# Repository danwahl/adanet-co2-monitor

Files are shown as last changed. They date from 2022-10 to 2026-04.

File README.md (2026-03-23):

# Adanet CO₂ Monitor

The ambient CO₂ level is important for at least three reasons:

1. Excessive CO₂ can lead to a [decline in cognitive ability and sleep quality](https://slatestarcodex.com/2018/08/23/carbon-dioxide-an-open-door-policy/)
2. CO₂ levels can be used to as a [proxy for good ventilation and COVID risk](https://www.cdc.gov/coronavirus/2019-ncov/community/ventilation.html#faq-53432-answer0)
3. You can [monitor climate change](https://www.climate.gov/news-features/understanding-climate/climate-change-atmospheric-carbon-dioxide) in real time!

The [Wirecutter-recommended](https://www.nytimes.com/wirecutter/reviews/best-home-air-quality-monitor/) CO₂ monitor for personal use is the [Aranet4](https://aranet.com/products/aranet4/), and if you're just looking for something reliable and can afford it ($250 as of writing), stop reading and go buy one of those (or for a _slightly_ cheaper option, one of [these](https://www.co2.click/)).

---

Still here? Congratulations on not taking the coward's way out. Now let's build a thing!

The Adanet CO₂ Monitor has the following features:

- CO₂ (ppm), temperature (°C), relative humidity (%), battery life (%), and pressure (hPa) sensing
- "Tri-color" E Ink screen (black, red, and white I guess?)
- Long-ish battery life (~several weeks on a single charge)
- USB-C charging (and programming!) interface
- Built-in Wi-Fi and Bluetooth for feature expansion (currently disabled in software) 

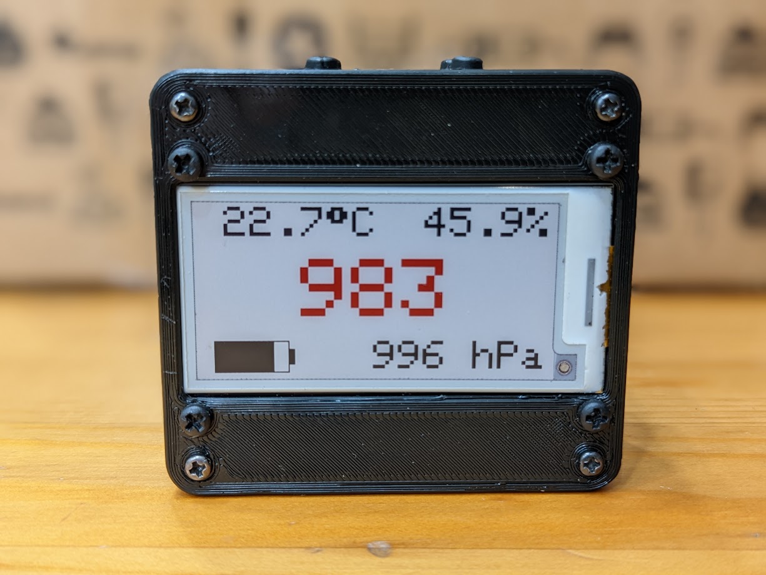
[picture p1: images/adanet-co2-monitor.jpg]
adanet-co2-monitor


## BOM

Most of the COTS parts are from [Adafruit](https://www.adafruit.com/) (hence the "Ada" prefix), but can be sourced through any of their distributors (and/or substituted for equivalents, but YMMV). Here's a snapshot of the [current BOM and pricing from Octopart](https://octopart.com/bom-tool/mcNhRVmk):

| Qty |  MPN | Part Description | Unit Price | Batch Total |
|:---:|:----:|:---:|:---:|:---:|
| 1 | 5477 | Adafruit Esp32-S3 Feather With 4Mb Flash 2Mb Psram - Stemma Qt / Qwiic | 17.5 | 17.5 |
| 1 | 4814 | Adafruit 2.13 Hd Tri-Color Eink / Epaper Display Featherwing - 250X122 Rw Panel With Ssd1680 | 24.95 | 24.95 |
| 1 | 5187 | Adafruit SCD-40 - True CO2 Temperature and Humidity Sensor | 49.5 | 49.5 |
| 1 | 4494 | Adafruit DPS310 Precision Barometric Pressure/Altitude Sensor - STEMMA QT/Qwiic | 6.95 | 6.95 |
| 1 | 2011 | Lithium Ion Battery - 3.7V 2000mAh | 12.5 | 12.5 |
| 2 | 4399 | STEMMA QT / Qwiic JST SH 4-Pin Cable - 50mm Long | 0.95 | 1.9 |
| | | | | 113.30 |

(Note that the [SCD-41](https://www.adafruit.com/product/5190) can be used as a drop-in replacement.)

In addition, you'll need several fasteners. Most come in the [Adafruit 3299](https://www.adafruit.com/product/3299) kit, but this is overkill (only 20 out of the 380 pieces are used), so you may have better luck at a hardware store [or](https://smile.amazon.com/gp/product/B018TH1NEM) [on](https://smile.amazon.com/gp/product/B012TAF8AK) [Amazon](https://smile.amazon.com/gp/product/B08F1XFQ7R). Either way, you'll need:

| Qty | Part Description | Material |
|:---:|:---:|---|
| 8 | M2.5 Hex Nut | Nylon |
| 8 | M2.5 x 6mm Screw | Nylon |
| 4 | M2.5 x 6mm M-F Hex Standoff | Nylon |
| 4 | M2.6 x 5mm Self-Tapping Screw | Steel |

I also bought the self-tapping screws in [a kit](https://smile.amazon.com/dp/B081DVZMHH), but there are [other](https://smile.amazon.com/gp/product/B00GDYDCC0) [options](https://smile.amazon.com/gp/product/B01L7PDGXO) too.

Finally, you'll need to 3D print the "top" and "bottom" pieces. If you don't have a 3D printer, either ask someone who does (these are relatively easy parts), visit to a local maker space (maybe even [your library?](https://www.chipublib.org/maker-lab/)), or use a service like [(3D)Hubs](https://www.hubs.com/). (Note: I recommend printing the "top" upside down, both to get a smooth finish on the outside and to avoid unnecessary overhangs.)

If you want to modify the design or are just curious, the parametric model is available at [OnShape](https://cad.onshape.com/documents/5da5dcb1f603a01f8bec88c9/w/ca967a8a956dc66b8484bce3/e/ef1ece94c6975fbb49878b31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).

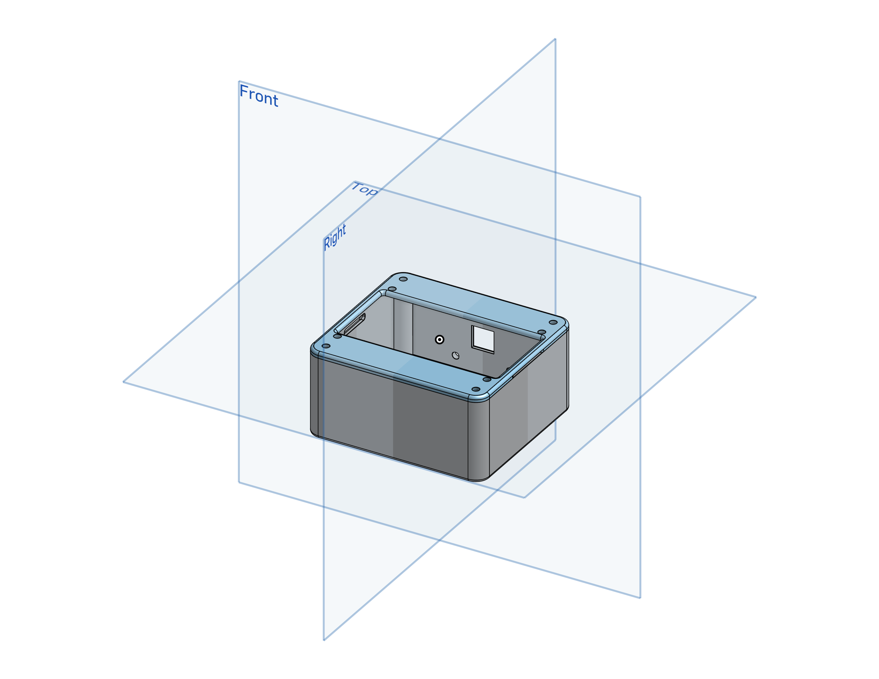
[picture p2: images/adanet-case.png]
adanet-case


## Assembly

First assemble the top and bottom of the case separately:

### Top

1. Attach the Feather board to the FeatherWing display as shown [here](https://learn.adafruit.com/adafruit-2-13-eink-display-breakouts-and-featherwings/wiring) (under "FeatherWing Connection")
2. Screw the assembly into the underside using 4 M2.5 x 6mm screws and 4 M2.5 hex nuts. Make sure that the flexible PCB on the FeatherWing (on the right in the image below) fits into the rectangular slot!

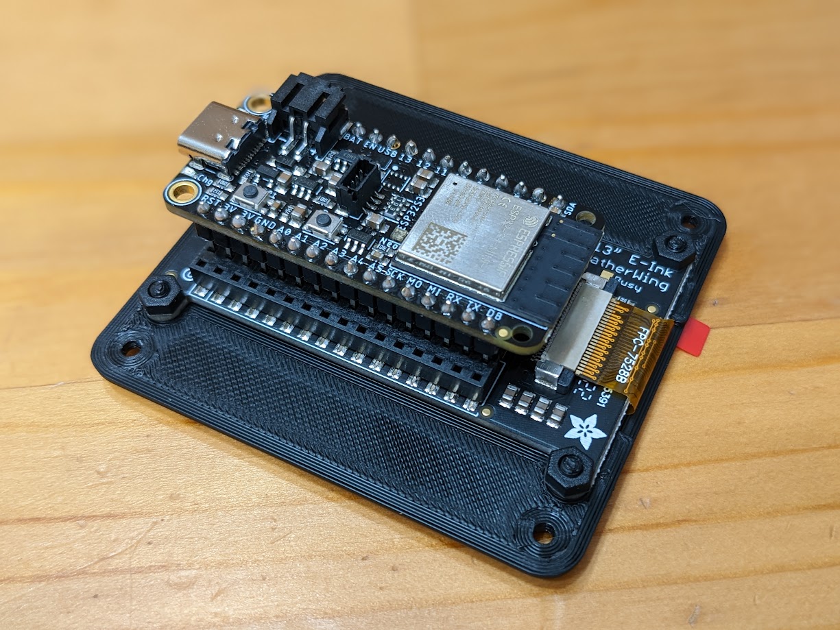
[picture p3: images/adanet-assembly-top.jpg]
adanet-assembly-top


### Bottom

1. Use 4 M2.5 x 6mm screws to attach the 4 M2.5 x 6mm M-F hex standoffs to the inside of the case (using the holes that border the the sensor slot)
2. Attach the 4-pin STEMMA QT cables to either side of the SCD4x board
3. Press the SCD4x board onto the four exposed standoffs, with the sensor facing "out" of the case, and use 2 M2.5 hex nuts to secure to the bottom two standoffs
4. Connect the DPS310 to the 4-pin STEMMA QT cable on the "right" (when facing the non-sensor side) of the SCD4x board
5. Use 2 M2.5 hex nuts to attach the DPS310 to the top two standoffs, back-to-back with the SCD4x so that the sensor is facing "in" (note: first apply Kapton/electrical tape to the back of the DPS310 to avoid shorting to the SCD4x)
6. Carefully insert the battery, which should fit snugly lengthwise, and adjacent to the bottom standoffs holding the SCD4x (note: you can use double-sided tape securely affix the battery to the case)

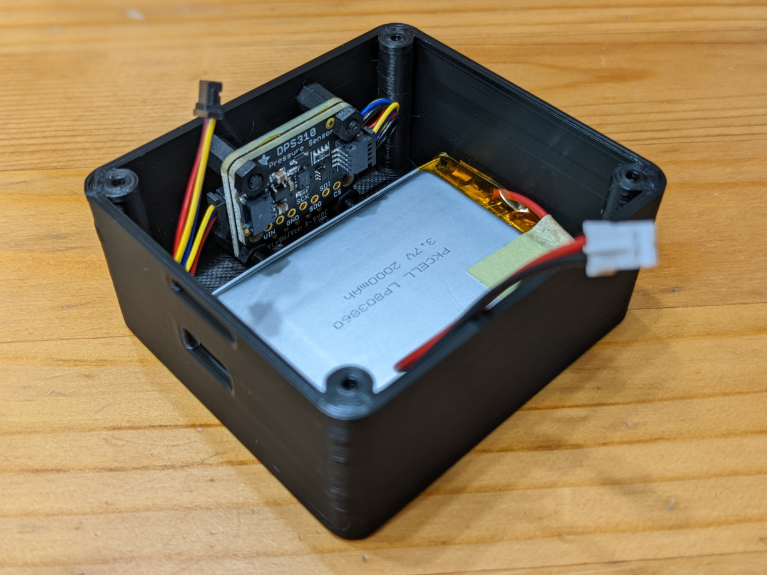
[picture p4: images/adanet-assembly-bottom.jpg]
adanet-assembly-bottom


Once both the top and bottom are assembled, connect the remaining 4-pin STEMMA QT and battery to the Feather board (middle and side connectors respectively). Close the lid to ensure a good fit, but don't install the 4 M2.3 x 5mm self-tapping screws until loading the firmware (as the BOOT/DFU and Reset buttons are not externally accessible)!

Once complete, your final assembly should look like this:

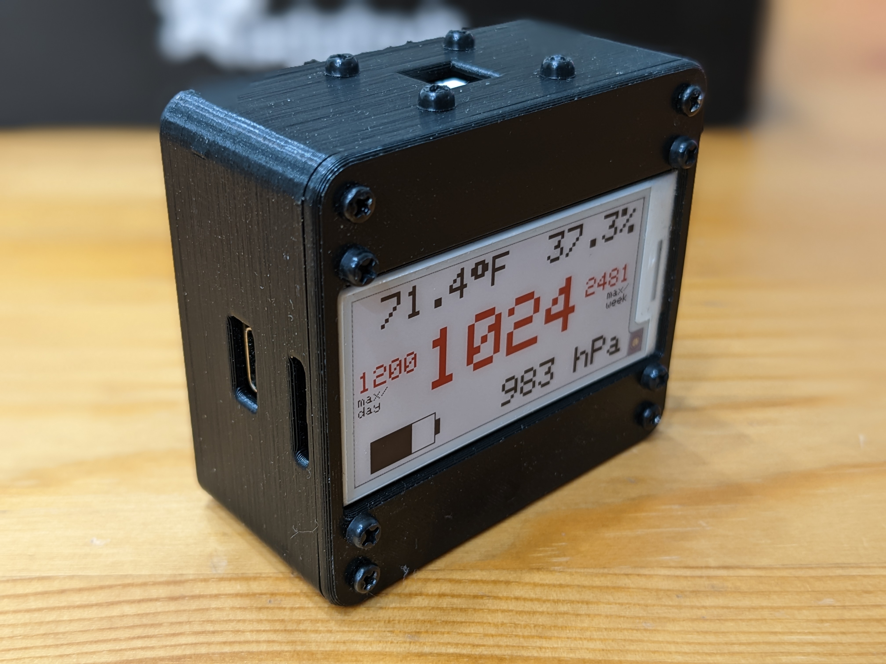
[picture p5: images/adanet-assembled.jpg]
adanet-assembled


## Firmware

The Arduino firmware (adanet-co2-monitor.ino) has been tested using the following software (and corresponding versions):

- Arduino IDE (v1.8.19 or v2.0.0)
- Adafruit DPS310 (v1.1.5)
- Adafruit EPD (v4.6.7)
- Adafruit LC709203F (v1.3.4)
- ESP32 Arduino (v3.3.5)
- Sensirion I2C SCD4x (v1.1.0)

### Development environment

To prepare your development environment:

1. Install [Arduino IDE](https://www.arduino.cc/en/software/) (and optionally the [VS Code extension](https://github.com/microsoft/vscode-arduino))
2. Follow [these instructions](https://docs.espressif.com/projects/arduino-esp32/en/latest/installing.html) to install the ESP32 Arduino library
3. Using the Library Manager (Tools/Manage Libraries...), install the remaining libraries listed above
4. Under Tools/Board (or Arduino: Board Config), select the "Adafruit Feather ESP32-S3 2MB PSRAM" option
5. In the same menu, change "USB Mode" to "Hardware CDC and JTAG" (see [here](https://github.com/espressif/arduino-esp32/issues/6762)) and "Upload Mode" to "UART0/Hardware CDC"
6. Plug in your Feather using the USB-C connector, and set the Port to match the one assigned by your OS (e.g. `COM5` on Windows, `/dev/ttyACM0` on Linux)

### Loading firmware

To load the firmware on the device:

1. Clone this repository somewhere sensible (Arduino projects are typically located in the `$HOME/Documents/Arduino` folder)
2. While holding the BOOT/DFU button, press and release the Reset button, putting the Feather into [ROM bootloader mode](https://learn.adafruit.com/adafruit-esp32-s2-feather/factory-reset)
3. If loading firmware for the first time, initialize and calibrate the sensor using the [adanet-init](adanet-init) program
4. In Arduino (or VS Code using the [Arduino extension](https://github.com/microsoft/vscode-arduino)), open the arduino-co2-monitor.ino file and click Upload (or run the Arduino: Upload task in VS Code)
5. Once finished, you may have to manually press the Reset button again to start the firmware

### Pseudocode

And that's it! The firmware does the following once every 180 seconds (the [fastest update rate](https://learn.adafruit.com/adafruit-2-13-eink-display-breakouts-and-featherwings/usage-expectations) supported by the E Ink screen):

1. Enable the SCD4x and DPS310 sensors, start measurements
2. Read battery charge state from the LC709203F sensor
3. Light sleep for 5 seconds while the initial CO₂ and pressure measurements are taking place
4. Update SCD4x with ambient pressure (the [nominal reason](http://www.co2meters.com/Documentation/AppNotes/AN149-Senseair-Pressure-Dependence.pdf) for the DPS310 sensor!)
5. Discard initial measurements (as per [SCD4x Low Power Operation](https://sensirion.com/media/documents/077BC86F/62BF01B9/CD_AN_SCD4x_Low_Power_Operation_D1.pdf)) and light sleep for another 5 seconds
6. Save new measurements and disable I2C power (turns off all sensors)
7. Enable the E Ink screen and update the display using the saved measurements
8. Deep sleep for ~170 seconds and repeat

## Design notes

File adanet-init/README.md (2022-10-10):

# Adanet Init

This is a helper program to initialize and calibrate an Adanet device. If using to calibrate, first update `CO2_AMBIENT` to the actual value (note that local CO₂ concentration is often higher than global ambient levels, e.g. [during nighttime in cities](https://www.sciencedirect.com/science/article/abs/pii/S0269749101002561?via%3Dihub).)

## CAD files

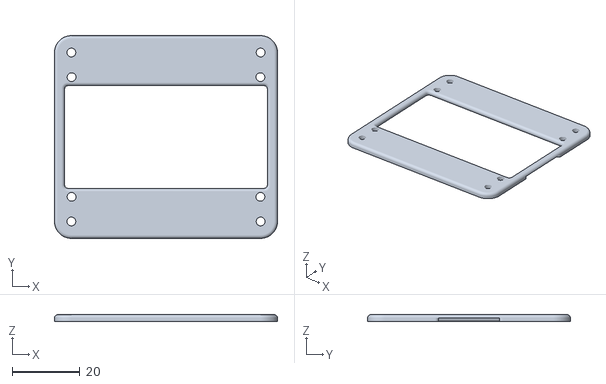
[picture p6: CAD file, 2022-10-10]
adanet-case-top.stl
66.0 x 60.0 x 2.00

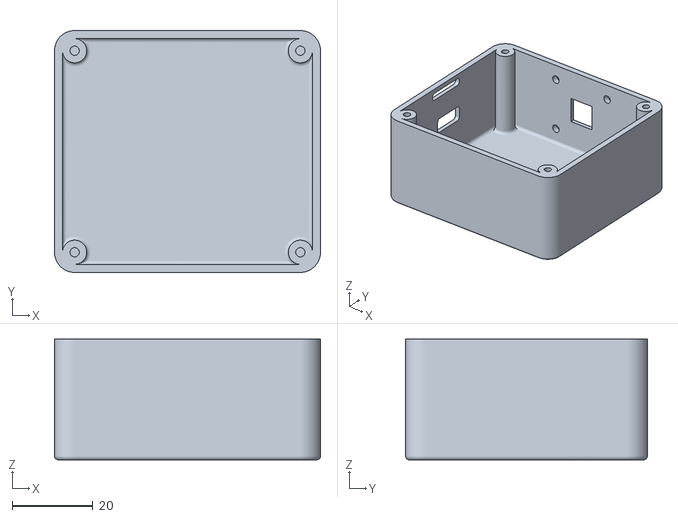
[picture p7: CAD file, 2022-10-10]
adanet-case-bottom.stl
66.0 x 60.0 x 30.0

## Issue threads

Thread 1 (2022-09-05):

Investigate Adafruit GFX fonts

danwahl, 2022-09-05:
Currently using the "classic" fixed-space bitmap font, but FreeMono would probably look better

danwahl, 2022-10-03:
Looked into this briefly and:

- The `FreeMono` font family isn't a big improvement over the built-in glxfont
- Would need to add a size bigger than the largest currently available (24pt)

Doesn't seem worth it for now

Closed 2022-10-03.

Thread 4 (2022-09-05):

Manual calibration software/instructions

danwahl, 2022-09-05:
Automatic Self Calibration is currently disabled, as per the [Low Power Operations](https://sensirion.com/media/documents/077BC86F/62BF01B9/CD_AN_SCD4x_Low_Power_Operation_D1.pdf) document:

> ASC is not supported for power cycled single shot operation.

It's not clear how often/badly the SCD4x goes out of calibration, but it might be necessary to create software/instructions for manual calibration.

Closed 2022-10-10.

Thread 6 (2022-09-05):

Address initial misc. software TODOs

danwahl, 2022-09-05:
- [x] Make `neoPixel` `static`, move initialization to `setup()` for consistency
- [x] Remove deprecated altitude correction once pressure sensor is verified
- [x] Improve (or in most cases, implement non-existent) error handling

Closed 2022-10-10.

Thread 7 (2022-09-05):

Investigate electrical modifications for reduced power consumption

danwahl, 2022-09-05:
- [ ] The E Ink screen has some low-hanging fruit, since both the `Reset` and `Busy` pins are [not currently wired up](https://learn.adafruit.com/adafruit-2-13-eink-display-breakouts-and-featherwings/pinouts) (see "Featherwing Connections"). See the [MagTag section on Arduion Sleep](https://learn.adafruit.com/adafruit-magtag/arduino-sleep) for more info
- [ ] Could remove the LED on the SCD4x (and DPS310). Also switch SCD4x to [Vin for sensor power](https://learn.adafruit.com/adafruit-scd-40-and-scd-41)?

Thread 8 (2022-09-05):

Verify that the SCD40 works as a drop-in replacement for the SCD41

danwahl, 2022-09-05:
The [Low Power Operation document](https://sensirion.com/media/documents/077BC86F/62BF01B9/CD_AN_SCD4x_Low_Power_Operation_D1.pdf) says:

> Power Cycled Single Shot Operation (SCD41 only)

But the firmware is not currently using single-shot operation, so I don't think this applies.

 Still, worth verifying before purchasing SCD40s in bulk!

danwahl, 2022-10-03:
I verified this, but still purchased the SCD41 for the first build round (since it was in stock). Given the functionality currently being used, I don't think it matters which of the SCD4x sensors is used. Keeping this open as a reminder to adjust the README accordingly.

danwahl, 2022-10-10:
I confirmed that the SCD40 works using the periodic measurement mode, same as the SCD41 (which is expected).

I then tried to use the "Power Cycled Single Shot Operation" as described in the above document (which required modifying the [arduino-i2c-scd4x](https://github.com/danwahl/arduino-i2c-scd4x/tree/idle-single-shot) library) but was getting suspicious temperature/humidity readings.

I'm not 100% sure that using the sensor in periodic measurement mode for two samples is a valid way to do low-power operation, and so I updated the README to recommend the SCD41 for now (so that a firmware fix could in theory resolve any issues).

Closed 2022-10-10.

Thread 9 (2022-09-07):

Use SD card slot for data logging

danwahl, 2022-09-07:
The FeatherWing has an SD card slot, nominally for storing graphics, but this could probably instead be used for logging. Since we only log once every three minutes, even a small card could could effectively be used indefinitely. Some considerations:

- Assuming a ~3 minute cycle (how exact is this?), and knowing the system time when the device was programmed, we could sort of get "accurate" timestamps without having a real time clock
  - This would work less well if the device was reset frequently, and would probably drift over time
- Not sure how the [SdFat library](https://github.com/greiman/SdFat) work, but each reset could potentially create a new CSV file, either with a datetime stamp or a sequential numbering scheme?
- The existing USB-C slot would need to be slightly enlarged to accommodate the width of the card, and it seems to be slightly off-centered on the FeatherWing as well
- The card would probably stick out of the case slightly, which seems fine

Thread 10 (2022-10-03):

Investigate different processor speeds

danwahl, 2022-10-03:
Seems like the processor speed could at least be turned down to 80 MHz to save power (if not all the way down to 10 MHz, though I remember reading somewhere that this might cause USB serial issues?)

danwahl, 2022-10-10:
Looked into this a bit, but couldn't get the system to reliably boot at 80 Mhz. Sometimes it works, but often it lands in the ROM bootloader _as if you double-clicked the reset button_ (as you would when loading [CircutPython](https://learn.adafruit.com/adafruit-esp32-s3-feather/circuitpython). I quickly checked if this was a debouncing issue on the reset pin itself, but the signal looked clean on the scope (and also it's not clear why it would work in 240 but not 80 MHz).

Leaving this open for now as a reminder to take a closer look at some point.

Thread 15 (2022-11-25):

Low battery mode to avoid draining battery

danwahl, 2022-11-25:
Right now, the system will continue running until the battery is totally drained, which is presumably not good for the longevity of the battery.

Instead, the device could read the battery level on startup, and if it is below a given threshold (5%?), activate a low battery mode. The mode would set a persistent flag, and then display an error message before going back into deep sleep. Each subsequent start would check both the battery level _and_ the flag, and only begin normal operation if the charge was above the threshold, otherwise going immediately back to sleep without updating the display.

This should prolong the healthy battery life considerably, though power draw in deep sleep is not zero, so a switch would be a better solution in the long term.

Closed 2022-11-29.

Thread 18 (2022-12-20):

What are the pros and cons of changing the frequency to 2 minutes?

stevevance, 2022-12-20:
Scenario: I want to test it in the elevator and I mentally counted the seconds since the last update, but the trip inside the elevator is quite short.

danwahl, 2022-12-20:
One additional con (the big one): the screen is only rated for updates every three minutes (see [here](https://learn.adafruit.com/adafruit-2-13-eink-display-breakouts-and-featherwings/usage-expectations)).

The actual code change would be pretty trivial (`DISPLAY_WAIT` from `180` to `120`). Happy to make you a custom build if you'd like to try it out, though this would probably void the "warranty." Worst case scenario, the [screen](https://www.adafruit.com/product/4814) breaks and you have to replace it (~$25).

stevevance, 2022-12-23:
I'll live with it the way it is :)

Two other ideas:
- When there is a method to store the data to a memory card, take readings every minute that can be reviewed on a computer at a later time.
- with those ~minutely readings, display them all at the next screen refresh (this would require a significant redesign of the screen layout).

danwahl, 2022-12-29:
Good ideas. On your points:

- See #9 re: storing on a memory card. I've only looked into this for a few minutes, so I'm not sure how difficult it would be (plausibly not very, though with some uncertainty around preventing corruption if the card is removed during a write).
- This would be cool, and maybe not too difficult--someone else suggested adding a sparkline, which might be easier to squeeze on the existing screen.

Overall, it wouldn't be too difficult to modify the code to take more measurements between screen updates, and I don't think it would consume _too_ much additional battery (pretty sure the screen has the largest current draw). I'd slightly favor the SD card approach, since that unlocks more of the device's functionality, and screen real estate is already pretty limited.

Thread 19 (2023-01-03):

What would cause an erroneous reading?

stevevance, 2023-01-03:
Today I saw an error message for the first time.

“Invalid sample detected”.
I checked the code: it looks like the error is thrown if the reading is zero.

check out the photo
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

danwahl, 2023-01-03:
It comes from [here](https://github.com/danwahl/adanet-co2-monitor/blob/v0.2.0/adanet-co2-monitor.ino#L322-L326) in the code.

Basically, the SCD4x (CO2 sensor) reading did not return an error, but the reported CO2 value was 0 ppm (which is an [invalid response](https://github.com/Sensirion/arduino-i2c-scd4x/blob/0.3.1/examples/exampleUsage/exampleUsage.ino#L113-L114)). I've seen this happen a few times, typically when I was handling the Adanet device during a measurement. I _think_ it's related to [the way photoacoustic NDIR sensors work](https://sensirion.com/media/documents/9E7DA521/627C2C8D/CD_IN_SCDxx_Transmissive_and_photoacoustic_NDIR_sensing_D1.pdf), but can't remember where I read that.

Did it go back to normal operation on the next update?

stevevance, 2023-01-03:
It went back to normal operation on the next update.

I wonder if the shopping cart caused an issue: The cart's wheels or axle had flat spots and the car was making the Adanet bounce on that rack.

danwahl, 2023-01-03:
Agreed, that's probably it re: the shopping cart. Good question re: why `0` is an invalid response. The [data sheet](https://web.archive.org/web/20221012210846/https://sensirion.com/media/documents/C4B87CE6/627C2DCD/CD_DS_SCD40_SCD41_Datasheet_D1.pdf) even says that `0` is within the valid range.

An uninformed guess: part of the sensor's measurement cycle is probably some sort of calibration of the microphone part of the photoacoustic assembly relative to the current ambient noise. If it got a particularly large reading due to a disturbance during this step, it might set its baseline noise level too high, and be unable to detect any CO2 signal on top of it, causing it to report `0`.

If that's correct, it would be able accurately detect the absence of CO2, at least in a relatively quiet environment...

stevevance, 2023-01-04:
thanks for the discussion! I'm gonna close this since I'm satisfied with the answer and I don't think it's worth refactoring the error message/detection.

Closed 2023-01-04.

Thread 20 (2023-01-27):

Sparklines

amakhlin, 2023-01-27:
Saw a comment about sparlines in another issue and thought it was a super neat idea! This is quite a high resolution display so it fits well with Tufte's original sparkline ideas.

To make room for a co2 reading sparkline I relocated the temperature field from upper left to lower right and got rid of relative humidity and pressure (never looked at them once but it could just be me...)

The 250 pixels across is just about perfect for a full day (24 hours) worth of data if we downsample by a factor of two. However, I ended up adding a label to clarify the timespan of the sparkline which took up 12 pixels leaving 238 pixel wide field. This is 2 pixels shy of the 240 we need but I figured it was close enough -- the full display ends up being 6 minutes short of 24 hours.

The vertical scale is determined by the maximum co2 reading over the last 24 hours which we already have on the display. Hopefully this relationship is clear because of similar labeling "24hr" and "max/24hr" and proximity of the labels.

I first tried a lightweight sparkline where each data point is represented by a single pixel:

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

But it turned out to be not super legible especially under less than perfect lighting conditions.

The second idea is a bar graph sparkline which looks a lot more legible:

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

@danwahl thoughts?

amakhlin, 2023-02-26:
Added pressure and humidity back in:

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

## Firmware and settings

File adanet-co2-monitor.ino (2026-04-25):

// #define DEBUG
#define USE_MAX17048
#define USE_TRICOLOR_MFGNR

#include <stdarg.h>
#include <stdio.h>

#include <Adafruit_DPS310.h>
#ifdef USE_MAX17048
#include "Adafruit_MAX1704X.h"
#else
#include <Adafruit_LC709203F.h>
#endif
#include <Adafruit_ThinkInk.h>
#include <Preferences.h>
#include <SensirionI2cScd4x.h>
#include <Wire.h>

static constexpr uint32_t VERSION_MAJOR = 0;
static constexpr uint32_t VERSION_MINOR = 2;
static constexpr uint32_t VERSION_PATCH = 2;

static constexpr int16_t EPD_DC = 10;    // can be any pin, but required!
static constexpr int16_t EPD_CS = 9;     // can be any pin, but required!
static constexpr int16_t EPD_RESET = -1; // can set to -1 and share with chip Reset (can't deep sleep)
static constexpr int16_t EPD_BUSY = -1;  // can set to -1 to not use a pin (will wait a fixed delay)

static constexpr int16_t CHAR_WIDTH = 6;  // width of a character in pixels
static constexpr int16_t CHAR_HEIGHT = 8; // height of a character in pixels

static constexpr int16_t HEADER_SIZE = 3; // text size of header
static constexpr int16_t BODY_SIZE = 6;   // text size of body
static constexpr int16_t FOOTER_SIZE = 3; // text size of footer
static constexpr int16_t ERROR_SIZE = 2;  // text size of error
static constexpr int16_t MAXVAL_SIZE = 2; // text size of max value
static constexpr int16_t MAXLBL_SIZE = 1; // text size of max label

static constexpr uint32_t DISPLAY_WAIT = 180; // wait between display updates in seconds

static constexpr uint32_t NUM_MEASUREMENTS = 2; // number of measurements to take
static constexpr uint32_t MEASUREMENT_WAIT = 5; // wait between checking measurement in seconds
static constexpr uint16_t CO2_LIMIT = 800;      // CDC CO2 ppm limit

static constexpr int16_t BATT_WIDTH = 3 * FOOTER_SIZE * CHAR_WIDTH;
static constexpr float BATT_WARN_LIMIT = 15.0f;
static constexpr float BATT_ERROR_LIMIT = 5.0f;

static constexpr size_t MESSAGE_SIZE = 256;

static constexpr uint8_t CO2_VAL_STRING_LEN = 10;

// number of seconds in a day: 60s * 60min * 24hrs = 86400
static constexpr int32_t UPDATES_PER_DAY = (86400 / DISPLAY_WAIT);
static constexpr int32_t UPDATES_PER_WEEK = UPDATES_PER_DAY * 7;

#ifdef USE_TRICOLOR_MFGNR
static ThinkInk_213_Tricolor_MFGNR display(EPD_DC, EPD_RESET, EPD_CS, -1, EPD_BUSY);
#else
static ThinkInk_213_Tricolor_RW display(EPD_DC, EPD_RESET, EPD_CS, -1, EPD_BUSY);
#endif

static SensirionI2cScd4x scd4x;

#ifdef USE_MAX17048
static Adafruit_MAX17048 maxlipo;
#else
static Adafruit_LC709203F lc;
#endif

static Adafruit_DPS310 dps;

static uint32_t error;
static char message[MESSAGE_SIZE];

static Preferences pref;

typedef enum
{
  ALIGN_LEFT,
  ALIGN_CENTER,
  ALIGN_RIGHT
} Alignment;

typedef enum
{
  ERROR_NONE,
  ERROR_CO2_SENSOR,
  ERROR_PRESSURE_SENSOR,
  ERROR_BATT_SENSOR,
  ERROR_LOW_BATT,
} Error;

RTC_DATA_ATTR static uint16_t co2HistoryFifo[UPDATES_PER_WEEK] = {0};
RTC_DATA_ATTR static uint16_t co2HistoryHead = 0;

RTC_DATA_ATTR static uint32_t errorPrev = ERROR_NONE;

void checkSCD4xError(const uint16_t scd4xError)
{
  if (scd4xError)
  {
    error = (ERROR_CO2_SENSOR << 16) | scd4xError;
    errorToString(scd4xError, message, MESSAGE_SIZE);
  }
}

void printfAligned(const uint8_t size, const Alignment alignment, const int16_t y, const uint16_t color, const char *fmt, ...)
{
  char buffer[MESSAGE_SIZE];
  va_list args;
  va_start(args, fmt);
  vsnprintf(buffer, sizeof(buffer), fmt, args);
  va_end(args);

  display.setTextSize(size);
  display.setTextColor(color);
  switch (alignment)
  {
  case ALIGN_CENTER:
    display.setCursor((display.width() - strlen(buffer) * size * CHAR_WIDTH) / 2, y);
    break;
  case ALIGN_RIGHT:
    display.setCursor(display.width() - 1 - strlen(buffer) * size * CHAR_WIDTH, y);
    break;
  // ALIGN_LEFT
  default:
    display.setCursor(0, y);
    break;
  }
  display.print(buffer);
}

// co2HisotryAdd() and co2HistoryRead() manipulate a circular buffer
// stored in co2HisotryFifo array located in RTC memory space which survives deep sleep
// co2HistoryHead points to where the next value will be stored
void co2HistoryAdd(const uint16_t co2)
{
  co2HistoryFifo[co2HistoryHead] = co2;
  ++co2HistoryHead %= UPDATES_PER_WEEK;
}

uint16_t co2HistoryRead(const uint16_t index)
{
  // following a call to co2HistoryAdd, co2HistoryHead points to the next available slot
  // therefore the latest/most recently updated value is located at (co2HistoryHead - 1)
  // and the value index steps back is located at (co2HistoryHead - 1 - index)
  int16_t idx = co2HistoryHead - 1 - index;

  // handle the wraparound of the circular buffer
  while (idx < 0)
  {
    idx += UPDATES_PER_WEEK;
  }

  return co2HistoryFifo[idx];
}

void computeCo2Max(uint16_t &dayMax, uint16_t &weekMax)
{
  dayMax = 0;
  weekMax = 0;

  for (uint16_t i = 0; i < UPDATES_PER_WEEK; i++)
  {
    if (i < UPDATES_PER_DAY)
    {
      if (co2HistoryRead(i) > dayMax)
      {
        dayMax = co2HistoryRead(i);
      }
    }
    if (co2HistoryRead(i) > weekMax)
    {
      weekMax = co2HistoryRead(i);
    }
  }
}

void formatCo2(const uint16_t primaryCo2Val, const uint16_t secondaryCo2Val, char *str)
{
  if ((primaryCo2Val > 9999 && secondaryCo2Val > 999) || (primaryCo2Val > 999 && secondaryCo2Val > 9999))
  {
    snprintf(str, CO2_VAL_STRING_LEN, "%.0fK", static_cast<float>(secondaryCo2Val) / 1000.f);
  }
  else
  {
    snprintf(str, CO2_VAL_STRING_LEN, "%u", secondaryCo2Val);
  }
}

void setup()
{
  // turn on i2c power
  digitalWrite(I2C_POWER, HIGH);

  // turn off neopixel power
  digitalWrite(NEOPIXEL_POWER, !NEOPIXEL_POWER_ON);

#ifdef DEBUG
  Serial.begin(115200);
  while (!Serial)
    delay(10);
  Serial.print("Adanet CO2 Monitor v");
  Serial.print(VERSION_MAJOR);
  Serial.print(".");
  Serial.print(VERSION_MINOR);
  Serial.print(".");
  Serial.println(VERSION_PATCH);
#else
  // TODO(drw): is this necessary?
  delay(1000);
#endif

  error = ERROR_NONE;

  pref.begin("adanet-co2", true);
  // get temperature display units preference from flash
  const int8_t tempUnits = pref.getChar("temp_units", 'C');
  pref.end();

float batt = 0.0f;
#ifdef USE_MAX17048
  // setup max17048 battery fuel gauge
  if (!maxlipo.begin())
  {
    error = ERROR_BATT_SENSOR << 16;
    snprintf(message, MESSAGE_SIZE, "Couldn't find Adafruit MAX17048, make sure a battery is plugged in");
  }

  if (error == ERROR_NONE)
  {
#ifdef DEBUG
    Serial.println(F("Found MAX17048"));
#endif
    esp_sleep_enable_timer_wakeup(1000000ull);
    esp_light_sleep_start();

    batt = maxlipo.cellPercent();
    maxlipo.hibernate();

#ifdef DEBUG
    Serial.print("Battery = ");
    Serial.println(batt);
#endif

    if (batt < BATT_ERROR_LIMIT)
    {
      error = ERROR_LOW_BATT << 16;
      snprintf(message, MESSAGE_SIZE, "Battery voltage too low, please charge");
    }
  }
#else
  // setup lc709203f battery fuel gauge
  if (!lc.begin())
  {
    error = ERROR_BATT_SENSOR << 16;
    snprintf(message, MESSAGE_SIZE, "Couldn't find LC709203F, make sure a battery is plugged in");
  }

  if (error == ERROR_NONE)
  {
#ifdef DEBUG
    Serial.println(F("Found LC709203F"));
#endif

    // TODO(drw): set with DPS310 value? (default temperature in i2c mode is 25C)
    lc.setTemperatureMode(LC709203F_TEMPERATURE_I2C);
#ifdef DEBUG
    Serial.print("Cell Temperature = ");
    Serial.println(lc.getCellTemperature());
#endif

    lc.setPackSize(LC709203F_APA_2000MAH);

    batt = lc.cellPercent();
    lc.setPowerMode(LC709203F_POWER_SLEEP);

#ifdef DEBUG
    Serial.print("Battery = ");
    Serial.println(batt);
#endif

    if (batt < BATT_ERROR_LIMIT)
    {
      error = ERROR_LOW_BATT << 16;
      snprintf(message, MESSAGE_SIZE, "Battery voltage too low, please charge");
    }
  }
#endif

  // setup dps310 pressure sensor
  if ((error == ERROR_NONE) && !dps.begin_I2C())
  {
    error = ERROR_PRESSURE_SENSOR << 16;
    snprintf(message, MESSAGE_SIZE, "Failed to find DPS");
  }

  if (error == ERROR_NONE)
  {
    dps.configureTemperature(DPS310_64HZ, DPS310_64SAMPLES);
    dps.configurePressure(DPS310_64HZ, DPS310_64SAMPLES);

    // setup scd4x co2 sensor
    Wire.begin();
    scd4x.begin(Wire, 0x62);

    checkSCD4xError(scd4x.startPeriodicMeasurement());
  }

  uint32_t measurements = 0;
  uint16_t co2 = 0, pressure = 0;
  float temperature = 0.0f, humidity = 0.0f;
  while ((error == ERROR_NONE) && (measurements++ < NUM_MEASUREMENTS))
  {
    // sleep while waiting for next measurement
#ifdef DEBUG
    delay(MEASUREMENT_WAIT * 1000);
#else
    esp_sleep_enable_timer_wakeup(MEASUREMENT_WAIT * 1000000ull);
    esp_light_sleep_start();
#endif

    if (dps.temperatureAvailable() && dps.pressureAvailable())
    {
      sensors_event_t temp_event, pressure_event;
      dps.getEvents(&temp_event, &pressure_event);

#ifdef DEBUG
      Serial.print(F("Temperature = "));
      Serial.println(temp_event.temperature);
      Serial.print(F("Pressure = "));
      Serial.println(pressure_event.pressure);
#endif

      pressure = static_cast<uint16_t>(pressure_event.pressure);
      checkSCD4xError(scd4x.setAmbientPressureRaw(pressure));
    }
    else
    {
      error = ERROR_PRESSURE_SENSOR << 16;
      snprintf(message, MESSAGE_SIZE, "Pressure data not available");
    }

    if (error == ERROR_NONE)
    {
      // try to read measurement
      checkSCD4xError(scd4x.readMeasurement(co2, temperature, humidity));
    }

#ifdef DEBUG
    if (error == ERROR_NONE)
    {
      Serial.print("CO2 = ");
      Serial.println(co2);
      Serial.print("Temperature = ");
      Serial.println(temperature);
      Serial.print("Humidity = ");
      Serial.println(humidity);
    }
#endif
  }

  if (error == ERROR_NONE)
  {
    checkSCD4xError(scd4x.stopPeriodicMeasurement());
  }

  if ((error == ERROR_NONE) && (co2 == 0))
  {
    error = ERROR_CO2_SENSOR << 16;
    snprintf(message, MESSAGE_SIZE, "Invalid sample detected");
  }

  // turn off i2c power
  digitalWrite(I2C_POWER, LOW);

#ifdef DEBUG
  if (error != ERROR_NONE)
  {
    Serial.print("Error = ");
    Serial.println(error, HEX);
    Serial.print("Message = ");
    Serial.println(message);
  }
  Serial.println();
#else
  // add co2 to history regardless of error in order to properly track time
  co2HistoryAdd(co2);

  // only update display if there is no error, or the error is different from previous
  if ((error == ERROR_NONE) || (error != errorPrev))
  {
    // setup display
    display.begin(THINKINK_TRICOLOR);

    // enum | orientation | USB
    // -----|-------------|-------
    //   0  | landscape   | right
    //   1  | portrait    | top
    //   2  | landscape   | left
    //   3  | portrait    | bottom
    display.setRotation(2);

    display.clearBuffer();

    const int16_t headerY = 0;
    const int16_t bodyY = (display.height() - BODY_SIZE * CHAR_HEIGHT) / 2;
    const int16_t maxValueY = display.height() / 2 - MAXVAL_SIZE * CHAR_HEIGHT;
    const int16_t maxLabelY = display.height() / 2;
    const int16_t footerY = display.height() - 1 - FOOTER_SIZE * CHAR_HEIGHT;
    if (error == ERROR_NONE)
    {
      const float dispTemp = (tempUnits == 'C') ? temperature : (temperature / 5.f * 9.f + 32.f);
      printfAligned(HEADER_SIZE, ALIGN_LEFT, headerY, EPD_BLACK, "%5.1f%c%c", dispTemp, 0xF7, tempUnits);
      printfAligned(HEADER_SIZE, ALIGN_RIGHT, headerY, EPD_BLACK, "%5.1f%%", humidity);

      uint16_t co2Color = co2 >= CO2_LIMIT ? EPD_RED : EPD_BLACK;
      printfAligned(BODY_SIZE, ALIGN_CENTER, bodyY, co2Color, "%u", co2);

      // co2 history
      uint16_t co2DayMax = 0;
      uint16_t co2WeekMax = 0;
      computeCo2Max(co2DayMax, co2WeekMax);

      char formattedCo2Str[CO2_VAL_STRING_LEN];
      formatCo2(co2, co2DayMax, formattedCo2Str);
      co2Color = co2DayMax >= CO2_LIMIT ? EPD_RED : EPD_BLACK;
      printfAligned(MAXVAL_SIZE, ALIGN_LEFT, maxValueY, co2Color, "%s", formattedCo2Str);

      formatCo2(co2, co2WeekMax, formattedCo2Str);
      co2Color = co2WeekMax >= CO2_LIMIT ? EPD_RED : EPD_BLACK;
      printfAligned(MAXVAL_SIZE, ALIGN_RIGHT, maxValueY, co2Color, "%s", formattedCo2Str);

      printfAligned(MAXLBL_SIZE, ALIGN_LEFT, maxLabelY, EPD_BLACK, "%s", "max/");
      printfAligned(MAXLBL_SIZE, ALIGN_LEFT, maxLabelY + MAXLBL_SIZE * CHAR_HEIGHT, EPD_BLACK, "%s", "day");
      printfAligned(MAXLBL_SIZE, ALIGN_RIGHT, maxLabelY, EPD_BLACK, "%s", "max/");
      printfAligned(MAXLBL_SIZE, ALIGN_RIGHT, maxLabelY + MAXLBL_SIZE * CHAR_HEIGHT, EPD_BLACK, "%s", "week");

      const uint16_t battColor = batt < BATT_WARN_LIMIT ? EPD_RED : EPD_BLACK;
      const int16_t x0 = FOOTER_SIZE * CHAR_WIDTH / 2;
      const int16_t y0 = footerY;
      const int16_t w = BATT_WIDTH;
      const int16_t h = FOOTER_SIZE * CHAR_HEIGHT;
      const int16_t x1 = x0 + w;
      const int16_t y1 = y0 + h;
      display.fillRect(x0, y0, static_cast<int16_t>(batt / 100.0f * static_cast<float>(w)), h, battColor);
      display.drawRect(x0, y0, w, h, battColor);
      display.fillRect(x1, y0 + h / 4, FOOTER_SIZE * CHAR_WIDTH / 4, h / 2, battColor);
      printfAligned(FOOTER_SIZE, ALIGN_RIGHT, footerY, EPD_BLACK, "%u hPa", pressure);
    }
    else
    {
      printfAligned(ERROR_SIZE, ALIGN_LEFT, 0, EPD_BLACK, "%012llX", ESP.getEfuseMac());
      printfAligned(ERROR_SIZE, ALIGN_RIGHT, 0, EPD_BLACK, "v%u.%u.%u", VERSION_MAJOR, VERSION_MINOR, VERSION_PATCH);
      printfAligned(ERROR_SIZE, ALIGN_LEFT, ERROR_SIZE * CHAR_HEIGHT, EPD_RED, "Error: %08X", error);
      printfAligned(ERROR_SIZE, ALIGN_LEFT, ERROR_SIZE * CHAR_HEIGHT * 2, EPD_RED, message);
    }

    display.display(true);
  }

  // store previous error
  errorPrev = error;

  esp_sleep_enable_timer_wakeup((DISPLAY_WAIT - measurements * MEASUREMENT_WAIT) * 1000000ull);
  esp_deep_sleep_start();
#endif
}

void loop()
{
  // shouldn't reach here during normal operation
  delay(10);
}

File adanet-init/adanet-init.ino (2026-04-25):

#define USE_MAX17048
#define USE_TRICOLOR_MFGNR

#include <stdarg.h>
#include <stdio.h>

#include <Adafruit_DPS310.h>
#ifdef USE_MAX17048
#include "Adafruit_MAX1704X.h"
#else
#include <Adafruit_LC709203F.h>
#endif
#include <Adafruit_ThinkInk.h>
#include <Wire.h>
#include <Preferences.h>
#include <SensirionI2cScd4x.h>

static constexpr int16_t EPD_DC = 10;    // can be any pin, but required!
static constexpr int16_t EPD_CS = 9;     // can be any pin, but required!
static constexpr int16_t SRAM_CS = 6;    // can set to -1 to not use a pin (uses a lot of RAM!)
static constexpr int16_t EPD_RESET = -1; // can set to -1 and share with chip Reset (can't deep sleep)
static constexpr int16_t EPD_BUSY = -1;  // can set to -1 to not use a pin (will wait a fixed delay)

static constexpr int16_t CHAR_WIDTH = 6;  // width of a character in pixels
static constexpr int16_t CHAR_HEIGHT = 8; // height of a character in pixels

static constexpr uint32_t MEASUREMENT_WAIT = 5;   // wait between checking measurement in seconds
static constexpr uint32_t CALIBRATION_WAIT = 300; // wait between measurement start and calibration
static constexpr uint16_t CO2_AMBIENT = 430;      // ambient CO2 for calibration

static constexpr size_t MESSAGE_SIZE = 256;

#ifdef USE_TRICOLOR_MFGNR
static ThinkInk_213_Tricolor_MFGNR display(EPD_DC, EPD_RESET, EPD_CS, -1, EPD_BUSY);
#else
static ThinkInk_213_Tricolor_RW display(EPD_DC, EPD_RESET, EPD_CS, -1, EPD_BUSY);
#endif

static SensirionI2cScd4x scd4x;

#ifdef USE_MAX17048
static Adafruit_MAX17048 maxlipo;
#else
static Adafruit_LC709203F lc;
#endif

static Adafruit_DPS310 dps;

static Preferences pref;

char readSerialChar()
{
  while (!Serial.available())
    delay(10);
  String input = Serial.readStringUntil('\n');
  input.trim();
  return input.length() > 0 ? input.charAt(0) : '\0';
}

bool checkSCD4xError(const uint16_t scd4xError)
{
  if (scd4xError)
  {
    static char message[MESSAGE_SIZE];
    errorToString(scd4xError, message, MESSAGE_SIZE);
    Serial.println(message);
    return true;
  }
  return false;
}

void setup()
{
  // turn on i2c power
  digitalWrite(I2C_POWER, HIGH);

  // turn off neopixel power
  digitalWrite(NEOPIXEL_POWER, !NEOPIXEL_POWER_ON);

  Serial.begin(115200);
  while (!Serial)
    delay(10);
  Serial.println("Adanet Init");

  // setup display
  display.begin(THINKINK_TRICOLOR);

  // draw stripe pattern to test screen
  display.clearBuffer();
  for (int16_t x = 0; x < display.width() - 1; x += 2)
  {
    for (int16_t y = 0; y < display.height(); y++)
    {
      display.drawPixel(x, y, EPD_BLACK);
      display.drawPixel(x + 1, y, EPD_RED);
    }
  }
  display.display(true);

  const uint64_t efuseMac = ESP.getEfuseMac();
  Serial.print("ESP eFuse MAC: ");
  Serial.println(efuseMac, HEX);

  const uint32_t cpuFreq = getCpuFrequencyMhz();
  Serial.print("CPU Freq = ");
  Serial.print(cpuFreq);
  Serial.println(" MHz");

  float batt = 0.0f;
#ifdef USE_MAX17048
  // setup max17048 battery fuel gauge
  if (!maxlipo.begin())
  {
    Serial.println("Couldn't find Adafruit MAX17048, make sure a battery is plugged in");
  }

  Serial.println(F("Found MAX17048"));
  Serial.print("Version: 0x");
  Serial.println(maxlipo.getICversion(), HEX);

  delay(1000);

  batt = maxlipo.cellPercent();
  maxlipo.hibernate();

#else
  // setup lc709203f battery fuel gauge
  if (!lc.begin())
  {
    Serial.println("Couldn't find LC709203F, make sure a battery is plugged in");
    return;
  }

  Serial.println(F("Found LC709203F"));
  Serial.print("Version: 0x");
  Serial.println(lc.getICversion(), HEX);

  lc.setThermistorB(3950);
  Serial.print("Thermistor B = ");
  Serial.println(lc.getThermistorB());

  lc.setPackSize(LC709203F_APA_2000MAH);
  lc.setAlarmVoltage(3.8);

  batt = lc.cellPercent();
  lc.setPowerMode(LC709203F_POWER_SLEEP);
#endif

  Serial.print("Battery = ");
  Serial.println(batt);

  // setup dps310 pressure sensor
  if (!dps.begin_I2C())
  {
    Serial.println("Failed to find DPS");
    return;
  }

  dps.configureTemperature(DPS310_64HZ, DPS310_64SAMPLES);
  dps.configurePressure(DPS310_64HZ, DPS310_64SAMPLES);

  // setup scd4x co2 sensor
  Wire.begin();
  scd4x.begin(Wire, 0x62);

  uint64_t scd4xSerial;
  if (checkSCD4xError(scd4x.getSerialNumber(scd4xSerial)))
  {
    return;
  }

  Serial.print("SCD4x Serial = ");
  Serial.println(scd4xSerial, HEX);

  // configure temperature units for display
  pref.begin("adanet-co2", false);
  Serial.println("Select temperature display units [c]elsius [f]arenheit? [c]");
  if (readSerialChar() == 'f')
  {
    pref.putChar("temp_units", 'F');
    Serial.println("Units set to Farenheit");
  }
  else
  {
    pref.putChar("temp_units", 'C');
    Serial.println("Units set to Celsius");
  }
  pref.end();

  Serial.println("Proceed to [c]alibration or [e]xit? [e]");
  if (readSerialChar() != 'c')
  {
    // wait a bit to make sure preferences have a chance to get commited to flash before exiting
    delay(1000);
    Serial.println("Done.");

    return;
  }

  // get serial input before starting calibration
  Serial.println("Perform factory reset? [n]");
  if (readSerialChar() == 'y')
  {
    Serial.println("Performing factory reset");

    if (checkSCD4xError(scd4x.performFactoryReset()))
    {
      return;
    }

    if (checkSCD4xError(scd4x.setAutomaticSelfCalibrationEnabled(0)))
    {
      return;
    }

    if (checkSCD4xError(scd4x.persistSettings()))
    {
      return;
    }

    if (checkSCD4xError(scd4x.reinit()))
    {
      return;
    }

    Serial.println("Factory reset complete");
  }

  Serial.println("Starting forced recalibration");

  if (checkSCD4xError(scd4x.startPeriodicMeasurement()))
  {
    return;
  }

  // pre-calibration measurement loop
  const unsigned long start = millis();
  while ((millis() - start) < (CALIBRATION_WAIT * 1000))
  {
    // sleep while waiting for next measurement
    delay(MEASUREMENT_WAIT * 1000);

    if (!dps.temperatureAvailable() || !dps.pressureAvailable())
    {
      Serial.println("Failed to read DPS");
      return;
    }

    sensors_event_t temp_event, pressure_event;
    dps.getEvents(&temp_event, &pressure_event);
    Serial.print(F("Temperature = "));
    Serial.println(temp_event.temperature);
    Serial.print(F("Pressure = "));
    Serial.println(pressure_event.pressure);

    if (checkSCD4xError(scd4x.setAmbientPressureRaw(pressure_event.pressure)))
    {
      return;
    }

    uint16_t co2 = 0;
    float temperature = 0.0f, humidity = 0.0f;
    if (checkSCD4xError(scd4x.readMeasurement(co2, temperature, humidity)))
    {
      return;
    }

    Serial.print("CO2 = ");
    Serial.println(co2);
    Serial.print("Temperature = ");
    Serial.println(temperature);
    Serial.print("Humidity = ");
    Serial.println(humidity);

    Serial.println();
  }

  if (checkSCD4xError(scd4x.stopPeriodicMeasurement()))
  {
    return;
  }
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

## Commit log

2022-09-26 Initial firmware with README and STLs
    [adanet-case-bottom.stl, adanet-case-top.stl]
2022-10-10 Pre release cleanup (#11)
    * Updating STLs to latest version with SD card slot
    * Restructuring the adanet-co2-monitor.ino sketch to improve error handling, add version info, and fix other minor issues
    * Adding initial draft of arduino-init.ino sketch, for initializing and calibrating newly built sensors
    * Updating README with latest changes (still need to change pics), reformatting error display screen
    * Cleanup of init app with better error handling, optional calibration. Adding minimal README
    * Using CDC air quality threshold of 800 ppm, minor formatting fixes
    * Moving battery test to top of init script, adding user input before factory reset and forced recalibration
    *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
    [adanet-case-bottom.stl, adanet-case-top.stl]
2022-10-24 Issue 1 readme update.am (#12)
    * adding missing library (NeoPixel)
    * updating readme with arduino ide version
    * removing NeoPixel header and updating readme
    [adanet-co2-monitor.ino, adanet-init.ino]
2022-10-25 Issue 2 freedom units.am (#13)
    * first try of C2F conversion
    * adding flash storage for temperature units display preference
    * flipping degree sign and units
    * addressing PR comments
    * addressing PR comments
    [adanet-co2-monitor.ino, adanet-init.ino]
2022-11-26 co2 daily and weekly max level tracking and display (#14)
    * adding max tracking using CircularBuffer placed in RTC memory -- this does not work
    * adding max tracking using a static history array in RTC memory
    * cleanup after rebasing
    * adding support for displaying large co2 values
    * dynamic adjustment of max day/week format based on co2 magnitudes
    * updating UPDATES_PER_WEEK after testing
    * addressing pr comments
    * simplyfing history tracking
    [adanet-co2-monitor.ino]
2022-11-29 Only update error screen with new errors to save battery, general cle… (#16)
    * Only update error screen with new errors to save battery, general cleanup, prep for next release
    * Fixing previous error storage and printout, lowering battery error threshold, adjusting temperature setting for battery fuel gauge
    * Updating README with SCD-40 recommendation, hardware options on Amazon, updated pseudocode
    * Entering deep sleep after initialization to avoid draining battery
    * Updating images to reflect firmware changes
    * Removing unused constant, adjusting test display pattern to fill screen
    [adanet-co2-monitor.ino, adanet-init.ino]
2022-11-29 Fixing build error caused by removal of SRAM_CS constant (#17)
    [adanet-co2-monitor.ino]
2026-03-23 Hw fw updates (#22)
    * Add support for new MAX17048 fuel gauge, MFGNR display variant, move battery reading after CO2 for accurate SOC
    * Move battery reading to init for early low-batt detection, update init script for new hardware and serial input
2026-04-25 Fix CO2 reading drift caused by setAmbientPressure unit change in SensirionI2cScd4x v1.0.0
    [adanet-co2-monitor.ino, adanet-init.ino]
